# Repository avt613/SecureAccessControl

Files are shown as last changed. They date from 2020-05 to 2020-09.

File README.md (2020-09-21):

# Secure RFID Access Control

The aim of this project is to make a secure access control system to open my front door with Mifare RFID tags.

If you set this up yourself, you will need to change the Mifare keys which are in the code.
My setup worked for a while and then just stopped working, throwing errors saying that it couldn't find the SD module. I think was because of the bad quality component.
I have stopped working with this project and am now focusing on my RPi-face-recognition project.

When you scan a tag the Uno reads the UID, authenticates Key A and B and the AC bits, and compares the data in block 2 of the selected sector to the file on the SD card with the name corresponting to the UID of the tag.

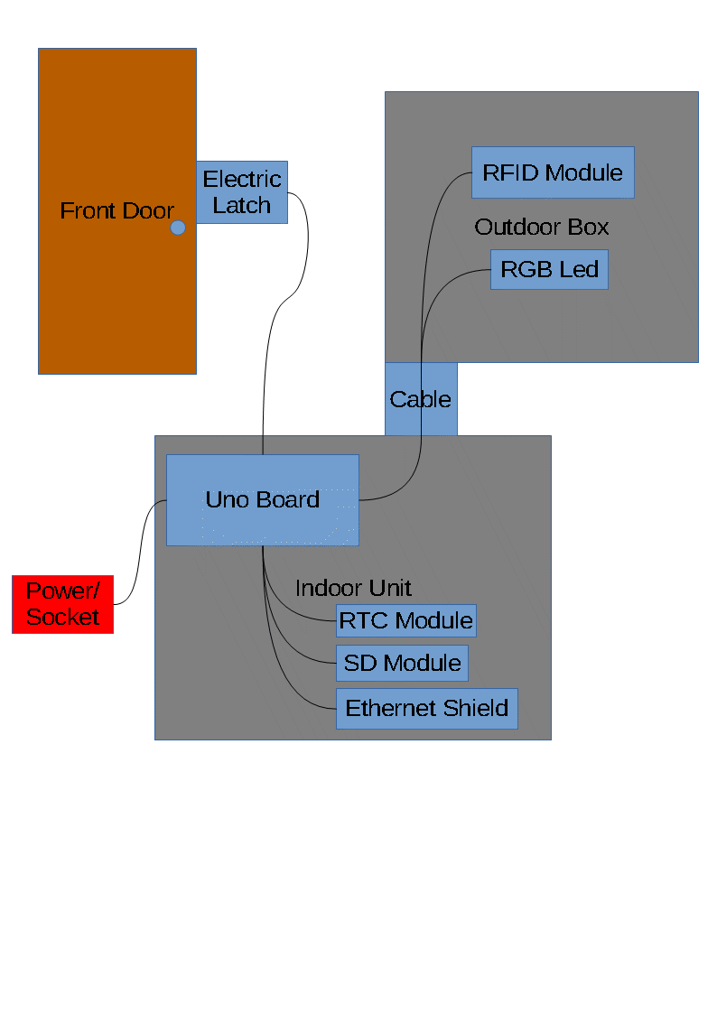
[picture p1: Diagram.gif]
Simple Diagram of System


## Circuit Diagram
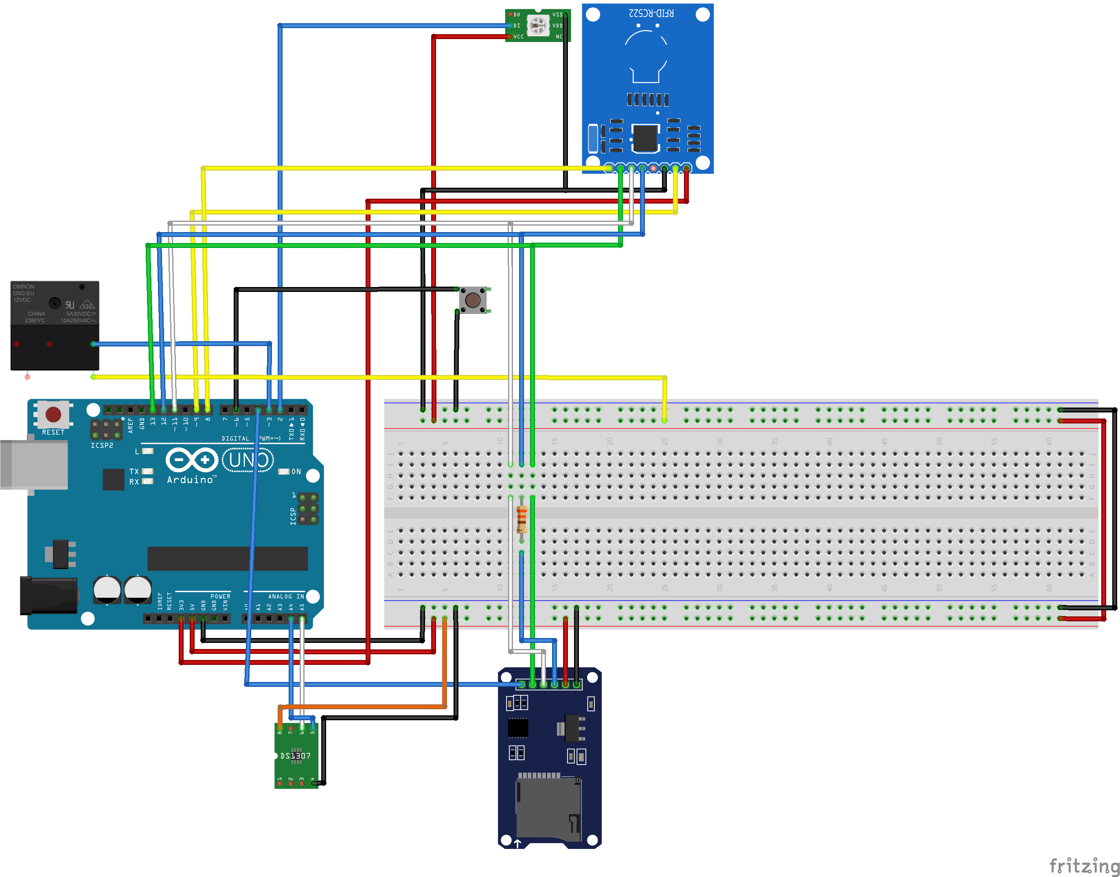
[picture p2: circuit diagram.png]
Circuit Diagram

The relay at the top left connects to the electric door lock which will unlock when the relay is powered.

I am using:
1. ELEGOO UNO (Same as Arduino Uno but cheaper)
1. MFRC-522 RFID IC Card Inductive Sensors Module 
1. Micro SD Card Module 
1. WS2812B 5050 RGB LED Strip 30 LEDs/M ws2812 IC Individual Addressable 5V
1. I2C RTC DS1307 AT24C32 Real Time Clock Module 

Any help or sugestions would be appreciated.

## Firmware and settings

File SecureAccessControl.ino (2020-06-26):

/* Error Codes
 *  3 - Failed to initialise SD Module
*   4 - failed to write to Log 
*   5 - Could not find RTC Module
*   6 - error opening "uidString".txt
*   7 - Could not find RC522 Module
*   8 - Could not add new card
*/

#include <Wire.h>                 // RTC Module
#include <RTClib.h>               // RTC Module
#include <Adafruit_NeoPixel.h>    // NeoPixel Strip
#include <SPI.h>                  // for the RFID and SD card module
#include <SD.h>                   // for the SD card
#include <MFRC522.h>              // for the RFID

// PINS
#define NeoPixelPin       2       // Which pin on the Arduino is connected to the NeoPixels?
#define relay             3       // Set Relay Pin
#define CS_SD             4       // define select pin for SD card module
#define prog              6       // Button pin for Programming Mode
#define CS_RFID           8       // define pins for RFID
#define RST_RFID          9       // define pins for RFID

#define NumNeoPixels      1       // How many NeoPixels are attached to the Arduino?
#define NeoPixelNotify    0       // Determine which LED to use as a notification LED
#define AccessGrantedTime 2000    // Time to keep the door unlocked for in milliseconds
#define AccessDeniedTime  1000    // Time to wait after an incorrect unlock attempt in milliseconds

byte    sector        =   2;                        // which sector to read on the RFID card
bool    programMode   =   false;                    // true if in programming mode
String  LogFile       =   "LOG.TXT";                // name of Log File
String  dataExt       =   ".TXT";                   // file extention for files holding card data
String  ACBits        =   " 0f 00 ff 69";           // AC bits the cards must have
String  uidString;                                  // Variable to hold the tag's UID
File    myFile;                                     // Create a file to store the data
byte    blockAddr     =   (4 * (sector + 1)) - 2;
byte    trailerBlock  =   (4 * (sector + 1)) - 1;
byte    buffer[18];
byte    size          =   sizeof(buffer);
MFRC522::MIFARE_Key keyA = {keyByte: {0x35, 0x35, 0x35, 0x32, 0x39, 0x34}};
MFRC522::MIFARE_Key keyB = {keyByte: {0x00, 0x00, 0xC8, 0xFF, 0x7F, 0x00}};
RTC_DS1307 rtc; 
MFRC522 rfid(CS_RFID, RST_RFID);
Adafruit_NeoPixel pixels(NumNeoPixels, NeoPixelPin, NEO_GRB + NEO_KHZ800);
static uint32_t Red   = pixels.Color(255,   0,   0);  // Setting easy name for common colours for the LED's 
static uint32_t Green = pixels.Color(  0, 255,   0);  // use pixels.setPixelColor(LED#, Color); to set a LED color (Red/ Green/ Blue/ Off)
static uint32_t Blue  = pixels.Color(  0,   0, 255);  // pixels.clear(); will set all LEDs to off
static uint32_t Off   = pixels.Color(  0,   0,   0);  // and then use pixels.show();

//*****************************************************************************************//

void setup() {  
  randomSeed(analogRead(0));  // used to generate sudo random numbers
  pinMode(relay, OUTPUT);
  digitalWrite(relay, LOW);   // Make sure door is locked
  pinMode(prog, INPUT_PULLUP);// Enable pin's pull up resistor
  Serial.begin(9600);         // Init Serial port
  // Setup NeoPixels
  pixels.begin();             // INITIALIZE NeoPixel strip object (REQUIRED)
  pixels.setBrightness(80);   // Set BRIGHTNESS (max = 255)
  pixels.clear();             // Set all pixel colors to 'off'
  pixels.show();
  
  // Setup RTC Module
  if (! rtc.begin()) {
    Serial.println(F("Couldn't find RTC"));
    ErrorCode(5);
  } 
  if (! rtc.isrunning()) {
    Serial.println(F("RTC is NOT running!"));
    // following line sets the RTC to the date & time this sketch was compiled
    rtc.adjust(DateTime(F(__DATE__), F(__TIME__)));
    // This line sets the RTC with an explicit date & time, for example to set
    // January 21, 2014 at 3am you would call:
    // rtc.adjust(DateTime(2014, 1, 21, 3, 0, 0));  
  }
  
  SPI.begin(); // Init SPI bus for RFID and SD modules
  // Setup SD card module
  if(!SD.begin(CS_SD)) {
    Serial.println(F("Initializing SD card failed!"));
    ErrorCode(3);  
  }
  rfid.PCD_Init(); // Setup RFID module
  rfid.PCD_DumpVersionToSerial();  // Show details of Card Reader
  if (rfid.PCD_PerformSelfTest() != 1){
      Serial.println(F("Couldn't find RC522"));
      ErrorCode(7);
  }
  
  Serial.print(F("Using key for A: "));
    for (byte i = 0; i < MFRC522::MF_KEY_SIZE; i++) {
        Serial.print(keyA.keyByte[i] < 0x10 ? " 0" : " ");
        Serial.print(keyA.keyByte[i], HEX);
    }
  Serial.println();
  Serial.print(F("Using key for B: "));
    for (byte i = 0; i < MFRC522::MF_KEY_SIZE; i++) {
        Serial.print(keyB.keyByte[i] < 0x10 ? " 0" : " ");
        Serial.print(keyB.keyByte[i], HEX);
    }
  Serial.println();
  Serial.print(F("Using AC bits  : "));
  Serial.println(ACBits);
  
  
  LogToSD(F("Startup Initialising Complete"));
  Serial.println(F("Startup Initialising Complete"));
  FlashNeoPixel(NeoPixelNotify, 1, 250, Red   );
  FlashNeoPixel(NeoPixelNotify, 1, 250, Blue  );
  FlashNeoPixel(NeoPixelNotify, 1, 250, Green );
}

//*****************************************************************************************//

void loop() {
  rfid.PCD_Init(); // Init MFRC522
  //look for new cards
  if(rfid.PICC_IsNewCardPresent()) {
    Serial.println("card found");
    readRFID();
    if(uidString != "00000000"){  // ignore if it didn't read the card properly
      if(digitalRead(prog) == LOW){
        programMode = true;
      }else{
        programMode = false;
      }
      pixels.setPixelColor(NeoPixelNotify, Blue);
      pixels.show();
      if(verifyRFIDCard() == 1){
        AccessGranted(AccessGrantedTime);
      }else{
        AccessDenied(AccessDeniedTime);
      }
      // Halt PICC
      rfid.PICC_HaltA();
      // Stop encryption on PCD
      rfid.PCD_StopCrypto1();
      ResetRFIDReadVariables();
    }
  }
  delay(10);
}

//*****************************************************************************************//

void readRFID() {
  uidString = "";
  rfid.PICC_ReadCardSerial();
  Serial.print(F("Card with uid detected: "));
  for (byte i = 0; i < 4; i++) {
        uidString += (rfid.uid.uidByte[i] < 0x10 ? "0" : "") + String(rfid.uid.uidByte[i],HEX);
    }
  Serial.println(uidString);
  LogToSD("Card with uid detected: " + uidString);
  delay(100);
}

//*****************************************************************************************//

int verifyRFIDCard(){
  if(SD.exists(uidString + dataExt) && programMode == true){
    Serial.println(F("Deleting card - Programming Mode"));
    LogToSD("Programming Mode - Deleting card: " + uidString);
    SD.remove(uidString + dataExt);
    return(2);
  }
  //check UUID
  if(!SD.exists(uidString + dataExt)){
    Serial.println(F("UID not recognized"));
    if (programMode == true) {
      Serial.println(F("Adding card - Programming Mode"));
      LogToSD("Programming Mode - Adding card: " + uidString);
      myFile=SD.open(uidString + dataExt,FILE_WRITE);
      myFile.close();
     }else{
      return(2);
     }
  }
  // Authenticate using key A
  //Serial.println(F("Authenticating using key A... "));
  MFRC522::StatusCode StatusKeyA = (MFRC522::StatusCode) rfid.PCD_Authenticate(MFRC522::PICC_CMD_MF_AUTH_KEY_A, trailerBlock, &keyA, &(rfid.uid));
  // Authenticate using key B
  //Serial.println(F("Authenticating using key B... "));
  MFRC522::StatusCode StatusKeyB = (MFRC522::StatusCode) rfid.PCD_Authenticate(MFRC522::PICC_CMD_MF_AUTH_KEY_B, trailerBlock, &keyB, &(rfid.uid));
  //Read AC bits
  //Serial.println(F("Authenticating using AC bits... "));
  MFRC522::StatusCode StatusAC = (MFRC522::StatusCode) rfid.MIFARE_Read(trailerBlock, buffer, &size);
  String ACString;
  for (byte i = 6; i < 10; i++) {
      ACString += (buffer[i] < 0x10 ? " 0" : " ") + String(buffer[i],HEX);
  }
  // Read card data
  //Serial.println(F("Reading card data..."));
  MFRC522::StatusCode StatusReadData = (MFRC522::StatusCode) rfid.MIFARE_Read(blockAddr, buffer, &size);
  String CardData;
  for (byte i = 0; i < 16; i++) {
      CardData += (buffer[i] < 0x10 ? "0" : "") + String(buffer[i],HEX);
  }
  
  // Check Keys AC
  if (StatusKeyA != MFRC522::STATUS_OK || StatusKeyB != MFRC522::STATUS_OK || StatusAC != MFRC522::STATUS_OK || ACString != ACBits) {
    Serial.println(F("Keys or AC not recognized"));
    return(3);
  }
  
  
  
  Serial.println(CardData);
  //Serial.println(F("Reading saved data..."));
  String SavedData = "";
  // Open file
  myFile=SD.open(uidString + dataExt);
  // If the file opened ok, read it
  if (myFile) {
    while (myFile.available()) {
    //Serial.write(myFile.read());
    SavedData += (char)myFile.read();
    }
    myFile.close();
    Serial.println(SavedData);
  }else {
    Serial.println("error opening " + uidString + dataExt);
    ErrorCode(6);  
  }
  if (StatusReadData != MFRC522::STATUS_OK || CardData != SavedData) {
    Serial.println(F("Reading card data failed or card data is inconsistent"));
    if (programMode == true) {
      Serial.println(F("Adding card - Programming Mode"));
    }else{
      return(6);
    }
  }
  
  
  // Write data to the block
  Serial.print(F("Writing data into block ")); Serial.println(blockAddr);
  String StringDataToWrite = "";
  byte DataToWrite[16];
  for (byte i = 0; i < 16; i++) {
      DataToWrite[i] = random(0, 255);
      if(DataToWrite[i] < 0x10){
        StringDataToWrite += "0";
      }
      StringDataToWrite += String(DataToWrite[i], HEX);
  }; 
  Serial.println(StringDataToWrite);
  MFRC522::StatusCode StatusWriteData = (MFRC522::StatusCode) rfid.MIFARE_Write(blockAddr, DataToWrite, 16);
  if (StatusWriteData != MFRC522::STATUS_OK) {
      Serial.print(F("Writing tag failed: "));
      Serial.println(rfid.GetStatusCodeName(StatusWriteData));
      return(4);
  }
  /*
  // reread card data
  Serial.println(F("Re-Reading card data..."));
  Status = (MFRC522::StatusCode) rfid.MIFARE_Read(blockAddr, buffer, &size);
  CardData = "";
  for (byte i = 0; i < 16; i++) {
      CardData += (buffer[i] < 0x10 ? "0" : "") + String(buffer[i],HEX);
  }
  Serial.println(CardData);
  if (Status != MFRC522::STATUS_OK || CardData != StringDataToWrite) {
    Serial.println(F("Could not verify card"));
    return(7);
  }*/
  
  Serial.println(F("Writing data to SD..."));
  SD.remove(uidString + dataExt);
  //Serial.println("Card removed with UID: " + uidString);
  // Open file
  myFile=SD.open(uidString + dataExt, FILE_WRITE);
  if (myFile) {
    myFile.print(StringDataToWrite);
    myFile.close();
  }else {
    Serial.println("error opening " + uidString + dataExt);
    ErrorCode(6);  
  }
  return(1);
}

//*****************************************************************************************//

void LogToSD(String DataToLogToSD){
      // Open file
      myFile=SD.open(LogFile, FILE_WRITE);
      // If the file opened ok, write to it
      if (myFile) {
        DateTime now = rtc.now(); //get current time
        // Serial.println(F("Log opened ok"));
        myFile.print(now.toString("YYYY.MM.DD, hh:mm:ss, "));
        myFile.println(DataToLogToSD);
        Serial.println(F("sucessfully written to log"));
        myFile.close();
        // Serial.println(F("Log closed"));
      }
      else {
        Serial.println("error opening " + LogFile);
        ErrorCode(4);  
      }
  }

//*****************************************************************************************//
  
void AccessGranted(int TimeDoorOpen){
  pixels.setPixelColor(NeoPixelNotify, Green);
  pixels.show();
  digitalWrite(relay, HIGH); // activate relay
  Serial.println(F("Access Granted"));
  LogToSD("Access Granted to card: " + uidString);
  delay(TimeDoorOpen);
  digitalWrite(relay, LOW); // de-activate relay
  pixels.setPixelColor(NeoPixelNotify, Off);
  pixels.show();
}

void AccessDenied(int LockoutTime){
  pixels.setPixelColor(NeoPixelNotify, Red);
  pixels.show();
  Serial.println(F("Access Denied"));
  LogToSD("Access Denied  to card: " + uidString);
  delay(LockoutTime);
  pixels.setPixelColor(NeoPixelNotify, Off);
  pixels.show();
}

//*****************************************************************************************//

void ErrorCode(int ErrorNum){
  //Serial.println("");
  Serial.print(F("Error Code: "));
  Serial.println(String(ErrorNum));
  Serial.println("----------------------------------------");
  pixels.clear();
  delay(500);
  FlashNeoPixel(NeoPixelNotify, 2, 500, Blue);
  FlashNeoPixel(NeoPixelNotify, ErrorNum, 500, Red);
  FlashNeoPixel(NeoPixelNotify, 2, 500, Blue);
  asm volatile ("  jmp 0"); //restart Uno
}


void FlashNeoPixel(int PixelNum, int NumberOfTimesToFlash, int FlashDelayTime, uint32_t FlashColor){
  
  for(int i = 0; i < NumberOfTimesToFlash; i++){
    pixels.setPixelColor(PixelNum, FlashColor);
    pixels.show();
    delay(FlashDelayTime);
    pixels.setPixelColor(PixelNum, Off);
    pixels.show();
    delay(FlashDelayTime);
  }
}

//*******************************************************************************************//

void ResetRFIDReadVariables(){
    uidString = "0";
    for (byte i = 0; i < 4; i++) {
      rfid.uid.uidByte[i] = 00;
    }
    for (byte i = 0; i < 16; i++) {
        buffer[i] = 0x00; 
    }
}

//*******************************************************************************************//

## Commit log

2020-02-13 reset uidstring after (not) unlocking
    [SecureAccessControl.ino]
2020-02-13 removed error logging loop
    [SecureAccessControl.ino]
2020-02-13 Made func for flashing LEDs
2020-03-04 Made function to reset read UID variables
    [SecureAccessControl.ino]
2020-03-07 changed setting for led strip
2020-03-29 Added RTC module
    Added restart on error
    Works out trailer block and data block from block number
    [SecureAccessControl.ino]
2020-03-30 Switched to KeyB, started adding in manager mode
2020-04-26 rolling code
    need to make sure that it works. unstable b/c memory low
    [SecureAccessControl.ino]
2020-04-27 rolling code works!!!
    need to add program mode and relay
2020-04-27 Added in programming mode and Relay
2020-04-27 Removed fingerprint sensor
2020-05-05 doesn't react to cards
    [SecureAccessControl.ino]
2020-05-07 New circuit diagrams
    [SecureAccessControl.fzz]
